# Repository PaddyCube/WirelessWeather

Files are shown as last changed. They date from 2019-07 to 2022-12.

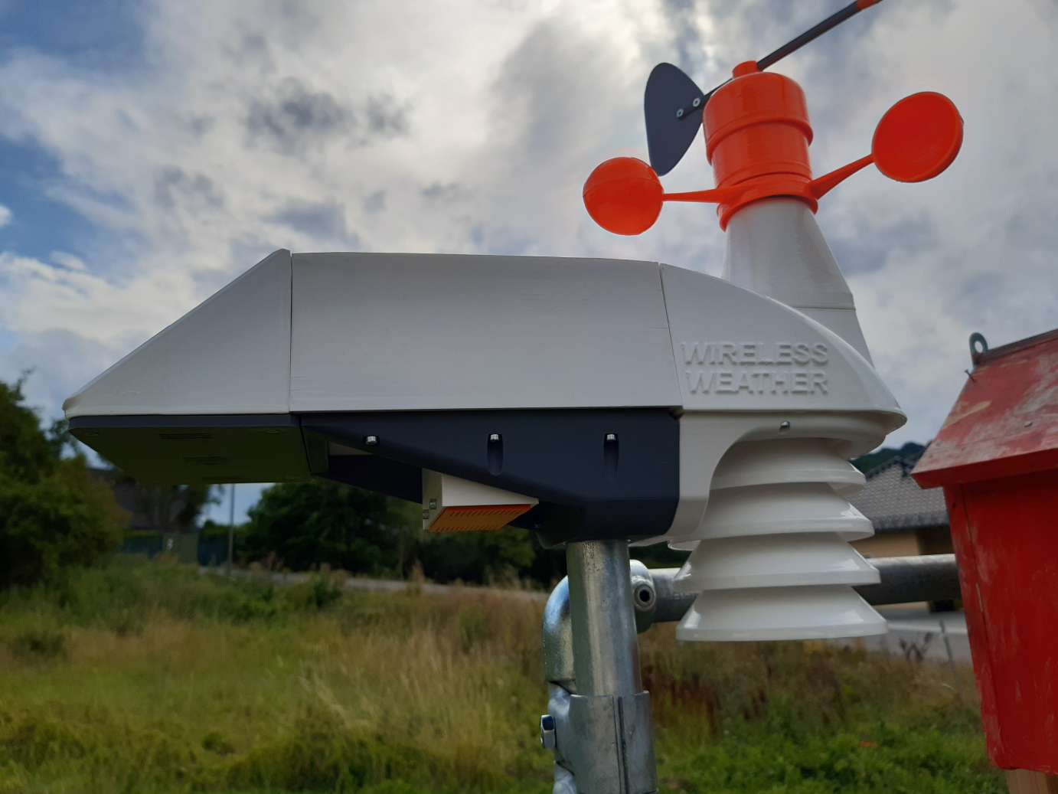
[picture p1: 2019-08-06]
Pictures/20190806_172357.jpg

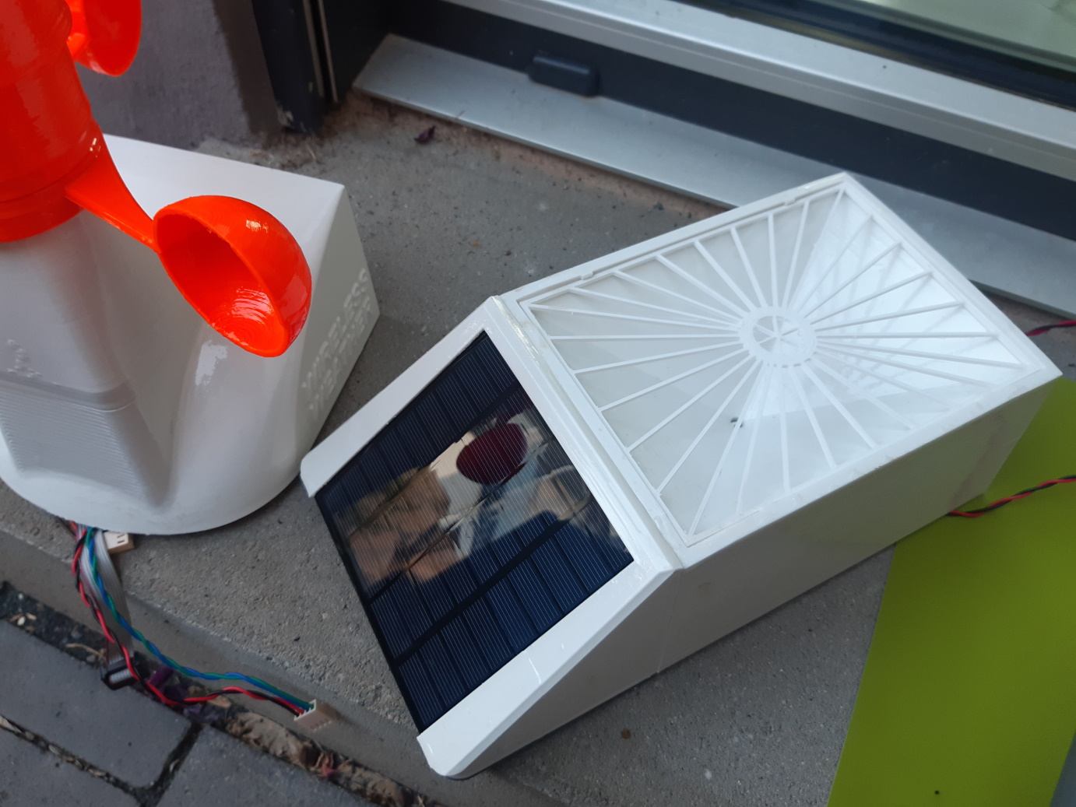
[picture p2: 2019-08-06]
Pictures/20190723_202226.jpg

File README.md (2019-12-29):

## Description
Build your own Wireless Weather station. This station includes:
- Temperature
- Humidity
- Pressure
- Rain Level
- Wind Speed
- Wind direction
- Battery monitor

There are three versions available: 
- One uses ESP8622 module and some ATTINYs
- one uses ESP32 and only one ATTINY for wind direction 
- one uses an Arduino Mini together with ATTINY24 for wind direction inside weather station and publish messages by 433 Mhz.

Code and schematics for any solution can be found in corresponding subfolders of folder 'code'

## Operation mode
### ESP8266
Wind speed and rain gets detected by pin change interrupt of ATTINYs. 
There is a power hungry device called WEMOS D1 mini pro, which deep sleeps most time. 
Every few minutes, it wakes up, collect data from other devices by I2C, send everything to your MQTT broker and sleeps again.

### ESP32
Wind speed and rain gets count by ULP co-processor of ESP32 module. Every few minutes, ESP32 wakes from deep sleep, read count values from ULP, power up I2C devices and sends everything to your MQTT broker. Then it sleeps again.

### Arduino Pro Mini
Because ESP devices are pretty power hungry, I wanted to build something more power saving. Therefore, a Arduino Pro Mini is used inside the weather station. Most time it sleeps and count wind and rain by interrupts. Every x minutes, it wakes up, power up I2C devices (BME280 and ATTINY24 for wind direction), reads values and send them using cheap 433MHz module. You find a working example based on ESP8266 module acting as a bridge between 433 Mhz and MQTT, so it receives data over 433MHz and publish them like before using MQTT. 

## Project site
You find all 3D printed parts at Thingiverse 
https://www.thingiverse.com/thing:3718078

A video is here https://youtu.be/xa0Dt5vs0kM

## BOM
This package includes software for the following components
### ESP8266
- 2x ATTINY85 (wind speed, rain and battery level)
- 1x ATTINY24 (wind direction)
- Wemos D1 Mini pro (or other ESP8266 device)
- 1x BME280
- Please find a complete BOM in BOM.txt file

Moreover you need some device to program ATTINYs. This can be done with any Arduino device. There are plenty of tutorials out there.

### ESP32
- 1x ATTINY24 (wind direction, see folder Wireless Weather)
- ESP32 (DOIT DevKit V1 with 30 GPIOs)
- 1x BME280

For further information, please see readme file in ESP32 folder

### Arduino Pro Mini
- 1x Arduino Pro Mini
- 1x ATTINY24 (wind direction)
- 1x BME280
- 1x 433MHz receiver, transmitter pair

You also need some code and device to receive the data and process them further. This can be done with any device, like Arduino, ESP8266, ESP32, Raspberry PI and so on. To get a complete working example, I added some code for ESP8266 (WEMOS D1 mini pro) which
acts as some kind of bridge between 433MHz and MQTT, meaning it receives the data send by Arduino Pro Mini and send them using MQTT protocol.

## Required Software
For ATTINYs, you need this package <br>
https://github.com/SpenceKonde/ATTinyCore <br>
https://github.com/rambo/TinyWire <br>

For ESP8266 and ESP32, I used this one <br>
https://arduino.esp8266.com/stable/package_esp8266com_index.json <br>
https://github.com/knolleary/pubsubclient <br>
https://github.com/adafruit/Adafruit_BME280_Library <br>

When using Arduino Pro mini, you need these packages as well <br>
https://github.com/rocketscream/Low-Power <br>
https://github.com/PaulStoffregen/RadioHead <br>
https://github.com/adafruit/Adafruit_BME280_Library <br>

## License
<br>Copyright (c) 2019 by Patrick Weber  

Private-use only! (you need to ask for a commercial-use)

You should have received a copy of the GNU General Public License
along with this program.  If not, see <http://www.gnu.org/licenses/>.

Private-use only! (you need to ask for a commercial-use)

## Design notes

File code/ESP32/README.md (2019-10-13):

## Description
This folder contains alternative code for ESP32 boards. By using this, less components are needed.

## Operation mode
Wind speed and rain gets detected by ESP32's built-in ULP co-processor while main ESP32 sleeps. 
Every few minutes, ESP32 wakes up, collect data from other devices by I2C, 
send everything to your MQTT broker and sleeps again.

## Project site
You find all 3D printed parts at Thingiverse 
https://www.thingiverse.com/thing:3718078

## BOM
This package includes software for the following components
- ESP32 board (I use ESP32 DEVKIT V1 with 30 GPIOs)

Because I didn't want to learn a new IDE, I used Arduino IDE to program everything (also ULP part), instead of esp-idf.
To upload ULP code with Arduino IDE, you need ulptool provided by duff2013 (https://github.com/duff2013/ulptool),
Arduino IDE itself and official packages for Arduino IDE provided by Espressif

## License
<br>Copyright (c) 2019 by Patrick Weber  

Private-use only! (you need to ask for a commercial-use)

You should have received a copy of the GNU General Public License
along with this program.  If not, see <http://www.gnu.org/licenses/>.

Private-use only! (you need to ask for a commercial-use)

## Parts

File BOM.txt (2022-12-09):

#---------------------------------------
# Screws and Nuts
#---------------------------------------
20x Knurled brass nuts (OD4mm, 5mm length) (https://www.aliexpress.com/w/wholesale-brass-insert-nut.html?switch_new_app=y)
30x Screws M3 (DIN 912)
4x Screw M4 x 60 (DIN 912)
4x Screw M4
2x Screw M5 x 40 (DIN 912)
7x counter sink screw M3 x 8 (DIN 7991)
14x Nuts M3
3x M3 threaded rod 105mm (Stevenson Screen)
8x Nuts M4
2x Nuts M5
1x Alu pipe 8mm OD 95mm
1x Alu Pipe 8mm OD 50mm
8x washer M3
4x wood or plastic screws (or knurled brass nuts + screws) (Anemometer)
2x KFL08 bearings (https://www.dold-mechatronik.de/Flanschlager-8mm-Aluminium-Druckguss-KFL08)
3x round magnet (neodym) 5mm OD

#---------------------------------------
# Electronics
#---------------------------------------
10 x Reed switch (NO)
1x Solar panel 110 x 125mm (https://www.ebay.de/itm/Mini-9V-1-5W-Sonnenkollektor-Solaranlage-Solar-Power-Panel-DIY-f%C3%BCr-Handy-Charger/272626734434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)
1x Battery case
3x AAA Nimh cells
4x Capacitor (electrolyte) 4,7uF
4x Capacitor (ceramic) 100nF
4x Capacitor (ceramic) 1uF
1x Schottky Diode SB 5100
2x Resistor 4k7
1x Resistor 1M5k
1x Resistor 220k
1x Resistor 100k
1x BME280

Next depends on the target solution you want to build

# ---- ESP8266 using ATTINYs for count wind/rain and wind direction
2x ATTINY85-20PU
1x ATTINY24A-PU
1x WEMOS D1 mini pro
1x MCP1702-3302 (https://www.reichelt.de/ldo-regler-fest-3-3-v-to-92-mcp-1702-3302-p90114.html?&trstct=pos_0)
1x MCP1702-5002 (https://www.reichelt.de/ldo-regler-fest-5-v-to-92-mcp-1702-5002-p90115.html)

# ---- ESP32 using ATTINY24 for wind direction
1x ATTINY24A-PU
1x ESP32 (DOIT DevKit V1 with 30 GPIOs)
1x MCP1826S-3302E (https://www.mouser.de/ProductDetail/Microchip-Technology/MCP1826S-3302E-AB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)
1x MCP1702-5002 

# ---- Arduino Pro Mini using ATTINY24 for wind direction
1x ATTINY24A-PU
1x Arduino Pro Mini 8Mhz, 3.3V (or ATMEGA328P)
1x MCP1702-3302 (https://www.reichelt.de/ldo-regler-fest-3-3-v-to-92-mcp-1702-3302-p90114.html?&trstct=pos_0)
1x MCP1702-5002 (https://www.reichelt.de/ldo-regler-fest-5-v-to-92-mcp-1702-5002-p90115.html)

#---------------------------------------
# Others
#---------------------------------------
Hot glue
Hot shrink tube
Wires
crimp connectors

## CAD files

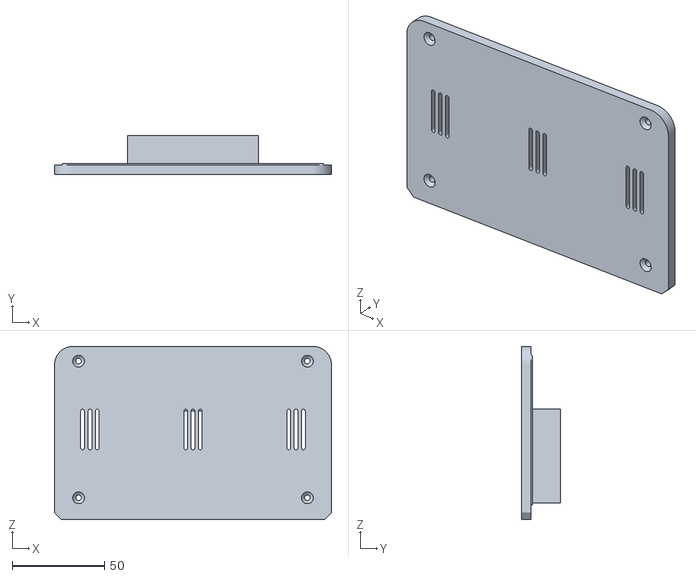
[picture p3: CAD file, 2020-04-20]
STL/Batteriefach.stl
150.0 x 21.0 x 93.8

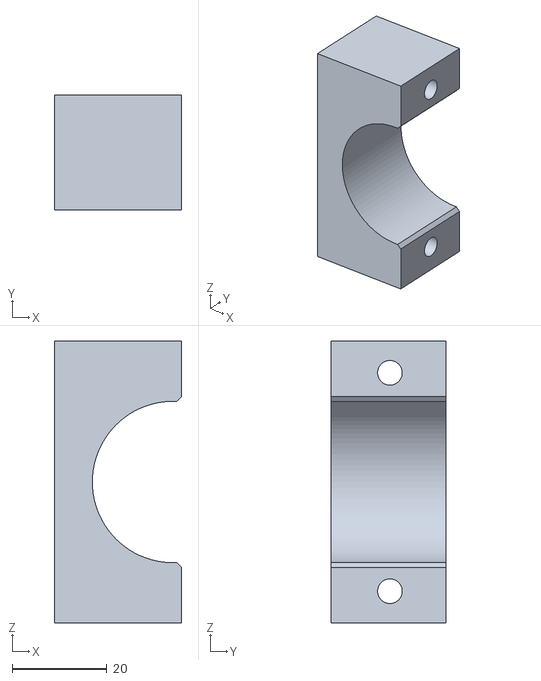
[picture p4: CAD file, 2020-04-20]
STL/Raingauge-Pole-Clamp.stl
26.8 x 24.2 x 59.4

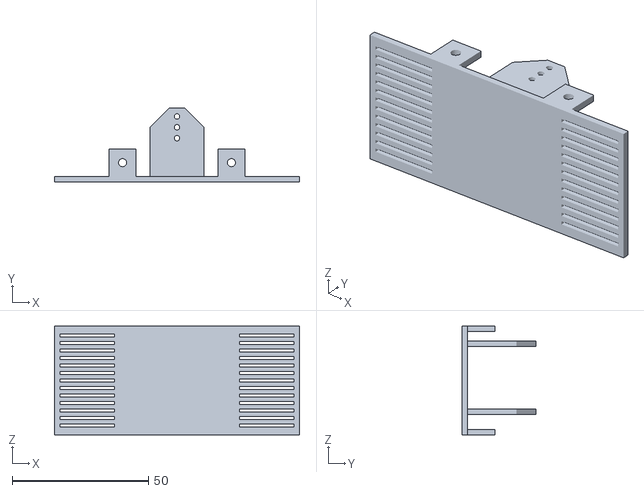
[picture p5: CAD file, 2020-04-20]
STL/Raingauge_Basis.stl
90.0 x 27.0 x 40.0

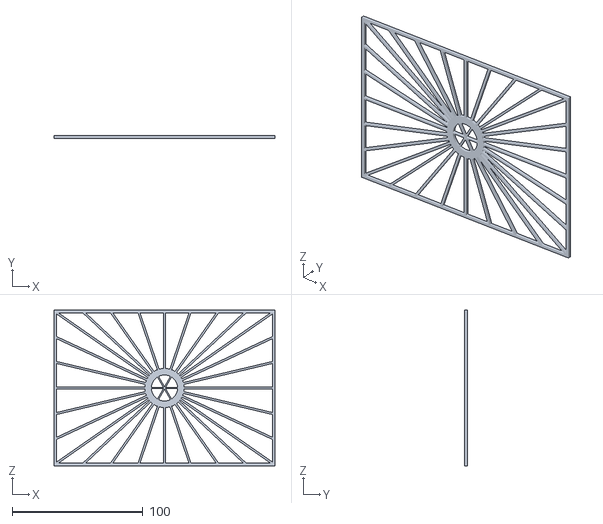
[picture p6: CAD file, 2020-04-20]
STL/Raingauge-Derb-Filter.stl
169.0 x 2.00 x 119.0

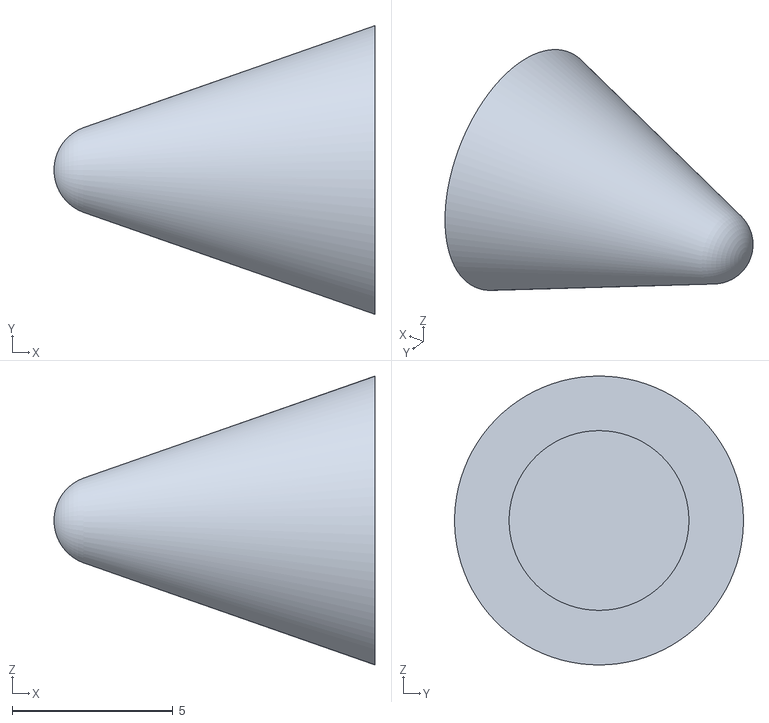
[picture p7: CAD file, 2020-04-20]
STL/Windfahne-Balance2.stl
10.0 x 8.99 x 9.00

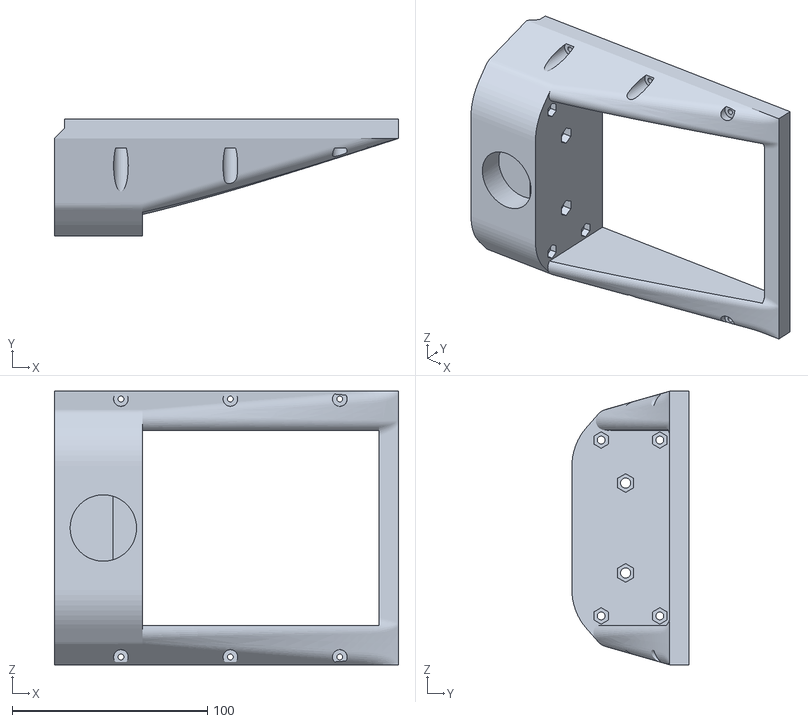
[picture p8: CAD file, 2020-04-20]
STL/Raingaube-lower-part.stl
176.0 x 60.0 x 140.0

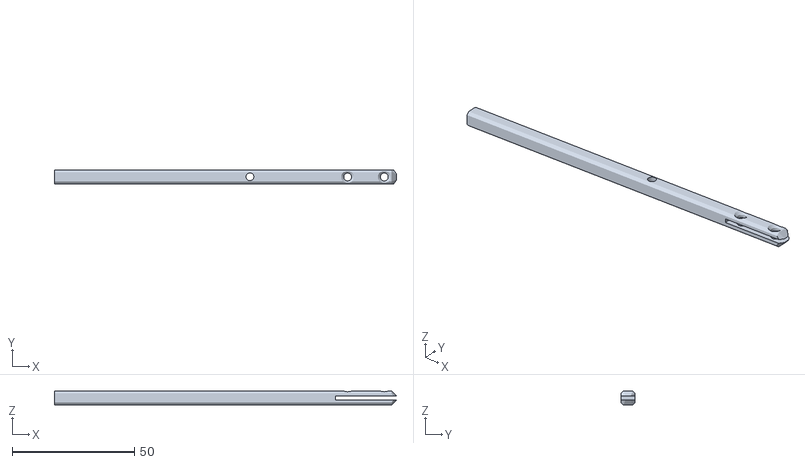
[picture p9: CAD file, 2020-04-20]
STL/Windfahne-Stab.stl
140.0 x 5.80 x 5.80

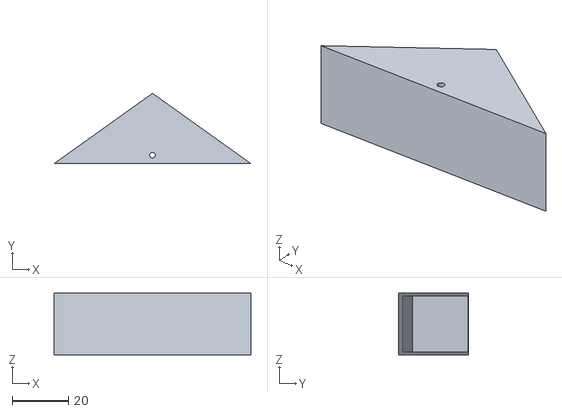
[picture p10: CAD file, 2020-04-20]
STL/Raingauge.stl
70.0 x 25.0 x 22.0

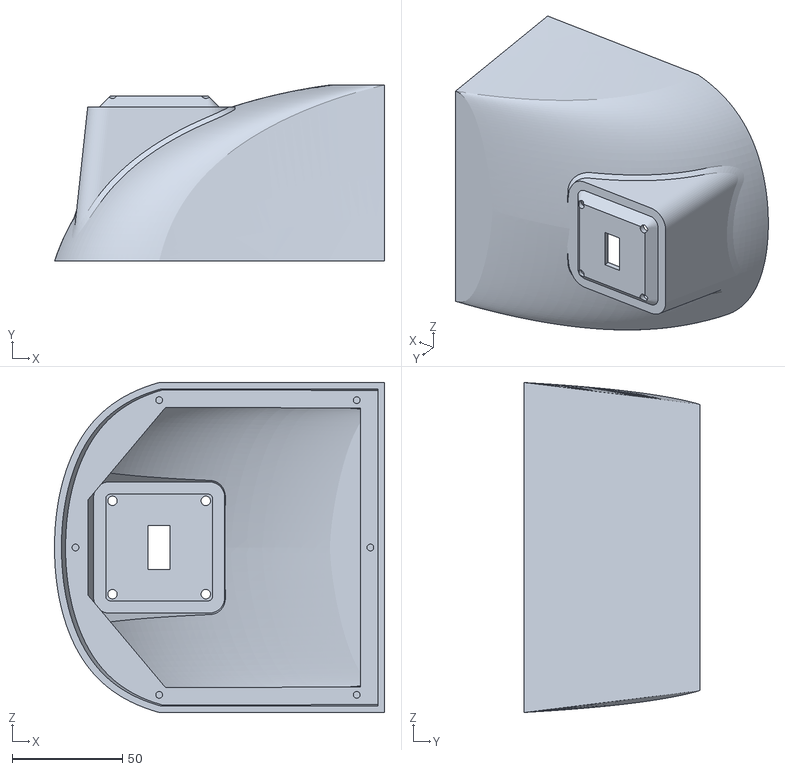
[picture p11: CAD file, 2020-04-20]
STL/Body7.stl
150.0 x 80.0 x 150.0

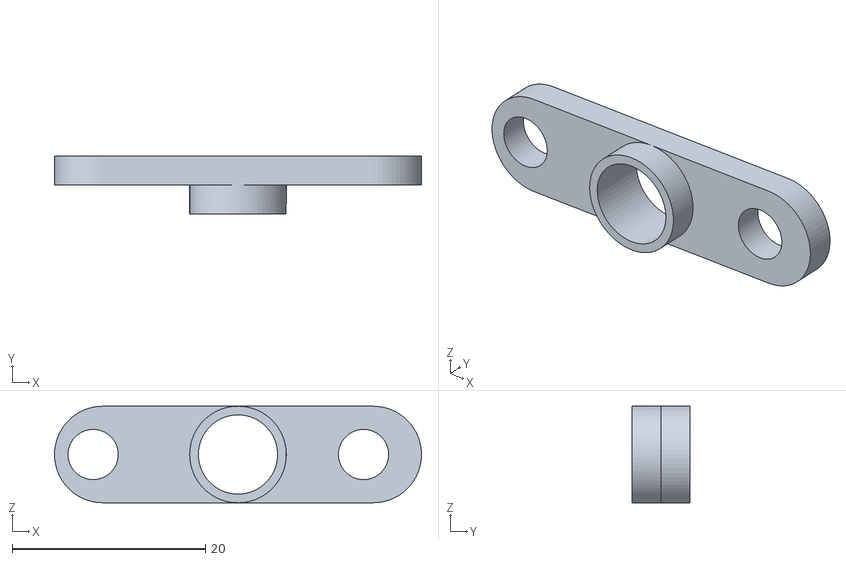
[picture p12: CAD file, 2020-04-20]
STL/Windfahne-Magnet.stl
38.0 x 6.00 x 10.0

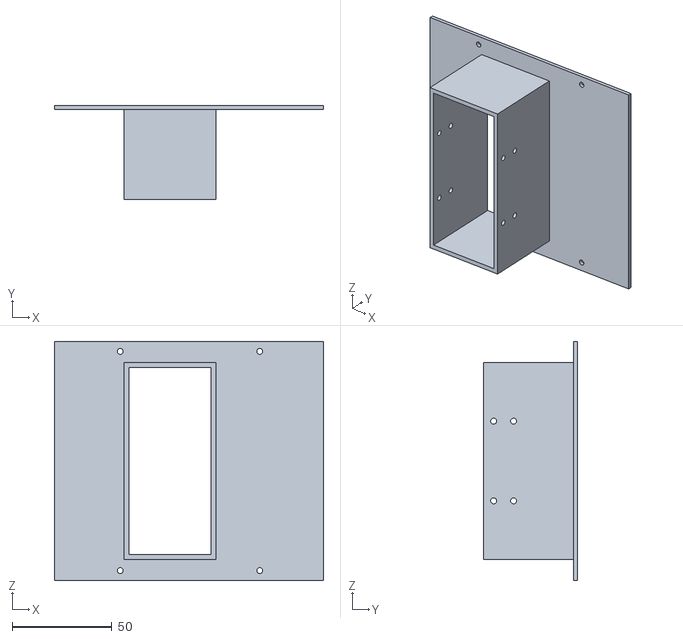
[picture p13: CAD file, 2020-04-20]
STL/Raingauge-mount-plate.stl
135.0 x 47.0 x 120.0

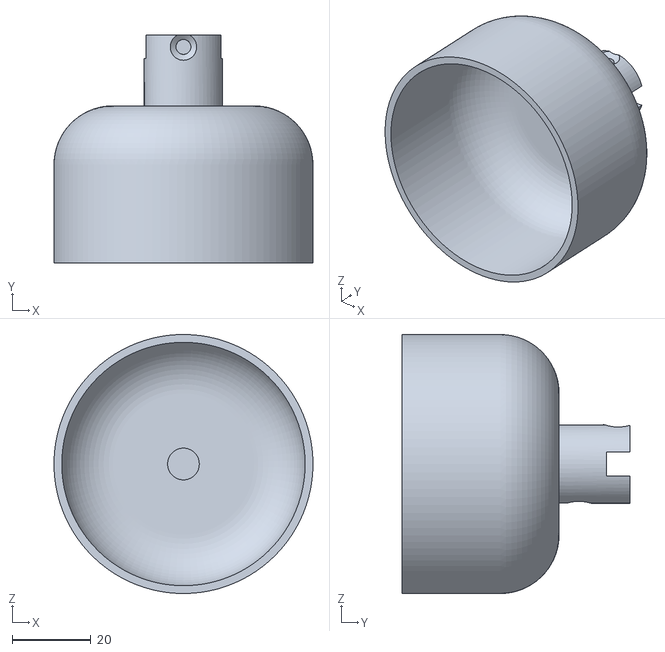
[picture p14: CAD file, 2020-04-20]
STL/Windfahne-Haube.stl
66.0 x 58.0 x 66.0

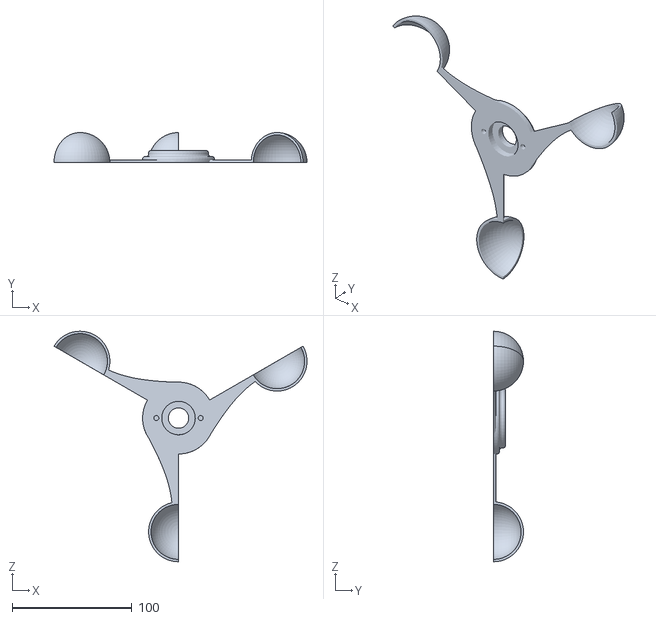
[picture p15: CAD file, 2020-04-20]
STL/Anemometer-Lagerschale.stl
211.2 x 25.0 x 192.5

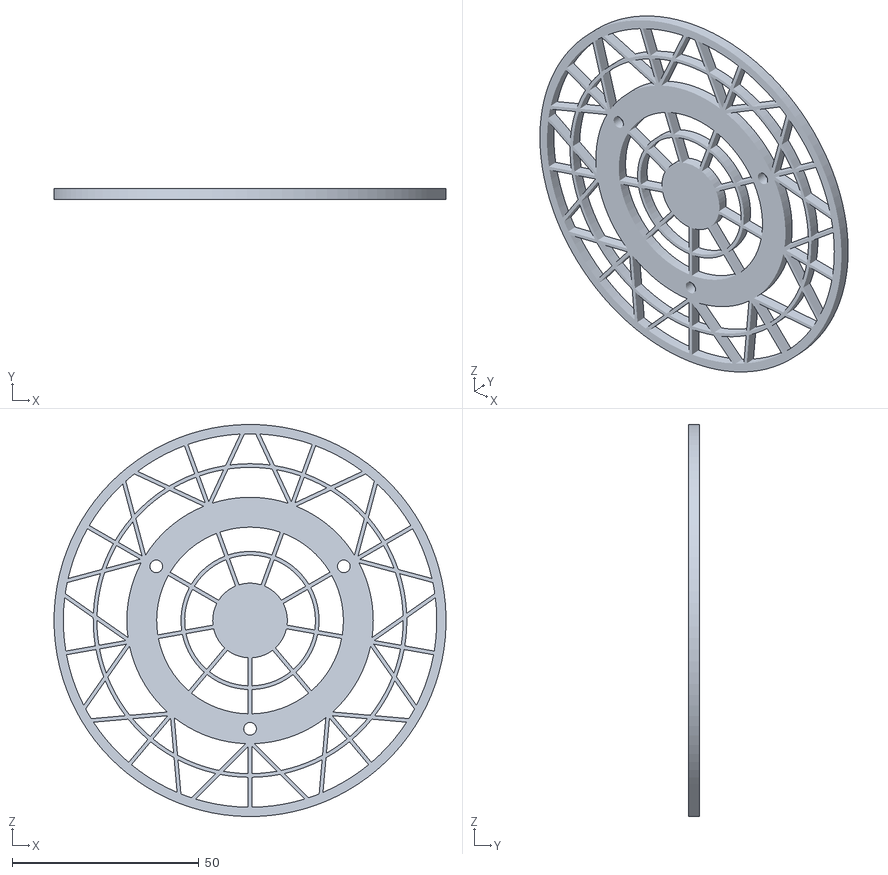
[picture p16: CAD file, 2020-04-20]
STL/Stevenson-Screen-Boden.stl
105.0 x 3.00 x 105.0

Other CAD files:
STL/Anemometer-lower-part v17.stl
STL/Sensor-Mount.stl
STL/Rain_Gauge_Cover.stl
STL/Solar-Modul.stl
STL/Anemometer-Lagerschale (1).stl
STL/Anemometer-lower-part v16.stl
STL/Anemometer-lower-part_v17.stl
STL/Platinenhalter.stl
STL/Stevenson-Screen-Mittelteil.stl
STL/Wetterstation-upper-part.stl
STL/Windfahne-Balance1.stl
STL/Windfahne-Deckel.stl
STL/Windfahne-Mast.stl
STL/Windfahne-Paddel.stl
STL/Windfahne-unten (1).stl
STL/Windfahne-unten.stl

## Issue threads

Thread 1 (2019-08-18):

PCB files cannot be opened.

theshadowsvk, 2019-08-18:
Hello PaddyCube, first of all, thank you for your great project !! All your solutions done in this project are simply perfect !!
My issue is, I can't oped the PCB files, especially those KiCad (it needs .zip filed them in some sort of way) or Eagle files, that this EDA wants them to be saved in Eagle 6.0 or above.
I'm trying to import these in EasyEDA. If you have some time, can you check it please ?

Thank you,
Lubos

PaddyCube, 2019-09-26:
Hello,
thank you for your feedback. Saldy I didn't note it, sorry for my late response. I'm not sure if I understand you right. I didn't create a PCB, its just a schematics drawing and I used KiCad to greate schematics. Currently, I don't know how to create a PCB file so you can manufacture it.

But as an additional note: I'm working on a ESP32 version of my weather station. That way, I can at least drop the two ATTINY85 because I use ULP co-processor to count while sleep.

theshadowsvk, 2019-09-26:
Oh sorry I thought they are pcb files. I already re-created the schematics and started creating pcb. Btw, I do some enhancements there like light sensor on i2c bus and other things like easier voltage regulator, solar charge

Esp32 supports various deepsleeps

PaddyCube, 2019-09-27:
May I ask which voltage regulator you use? MCP1703 does a good job but it delivers not enough current (250mA max). Sometimes, ESP8266 with all three Attinys will brownout and I must hard reset everything. I'm looking for a larger LDO for ESP32, so any suggestions?

PaddyCube, 2019-12-29:
Only schematics are available. I used prototype boards to solder everything together. Meaning there is no ready-to use PCB file

Closed 2019-12-29.

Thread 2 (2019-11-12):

Viewing received data

jeffreyclay, 2019-11-12:
I don't see anything mentioned regarding viewing or recording the data. Am I missing something?

PaddyCube, 2019-12-29:
Hi, this weather station uses MQTT to send data. So it is up to you to install a MQTT broker where the station can send data to.

There is a newer Version using a Arduino Pro Mini and a 433 MHz Transmitter to send data. Also there is some example code where ESP8266 device acts as receiver and send data (again) using MQTT. As a MQTT target, you can also use something like Thingspeak.com

Closed 2019-12-29.

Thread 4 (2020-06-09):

Schaltplan Arduino Mini

Marmi86, 2020-06-09:
Sehr schönes Projekt,
gib es für den Arduino mini/Nano auch ein Schaltplan für die Pinoutbelegung

Mfg
Marco

notecp, 2021-01-13:
So geht es mir auch, klasse Projekt.
Ich würde es ebenfalls nachbauen wollen und würde mich an KiCAD und Platinenlayout versuchen wollen (und diese hier zur Verfügung stellen)... wenn ich sicher wüsste, was wie verbunden gehört. Ebenso was den 433MHz Receiver angeht.

VG
Christian

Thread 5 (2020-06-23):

screw length

corneliusweiss, 2020-06-23:
Hi,
thanks for sharing your project. I'd like to build a copy for me.

Can you share the screw length in the BOM.txt with us?

kind regards
Cornelius

leonundjulie, 2023-12-21:
Hi to all of you. I am ready to screw parts …. §D-printing finished last night :-)

However, is someone able to tell us new story-member the length of the different types of screws?

Regards from
Andreas

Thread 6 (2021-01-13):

Lichtsensor / Fassade in der Sonne?

notecp, 2021-01-13:
Hallo Paddy,

gibt es eine Planung / Möglichkeit einen Lichtsensor o.ä. sinnvoll in die Station zu Integrieren?
Falls ja, würde sich doch damit auch schnell berechnen lassen wo die Sonne aktuell steht und ob sie auch wirklich scheint, oder?

Alternativ habe ich mir überlegt müsste es doch auch möglich sein (ob sinnvoll bin ich mir nicht sicher) einen Temperaturfühler an der Ost, Süd und Westseite anzubringen und diesen mit dem bereits vorhandenen zu vergleichen. Somit müsste es möglich sein festzustellen, ob die Station von dieser Seite in der Sonne steht oder nicht, oder?

VG
Christian

AcidSubway, 2022-01-16:
da ich grad über diesem Projekt bin, wäre ein Lux-Sensor schon cool :D

leonundjulie, 2023-12-21:
Hast Du das Projekt umgesetzt? Ich suche gerade nach den Längen der Schrauben??

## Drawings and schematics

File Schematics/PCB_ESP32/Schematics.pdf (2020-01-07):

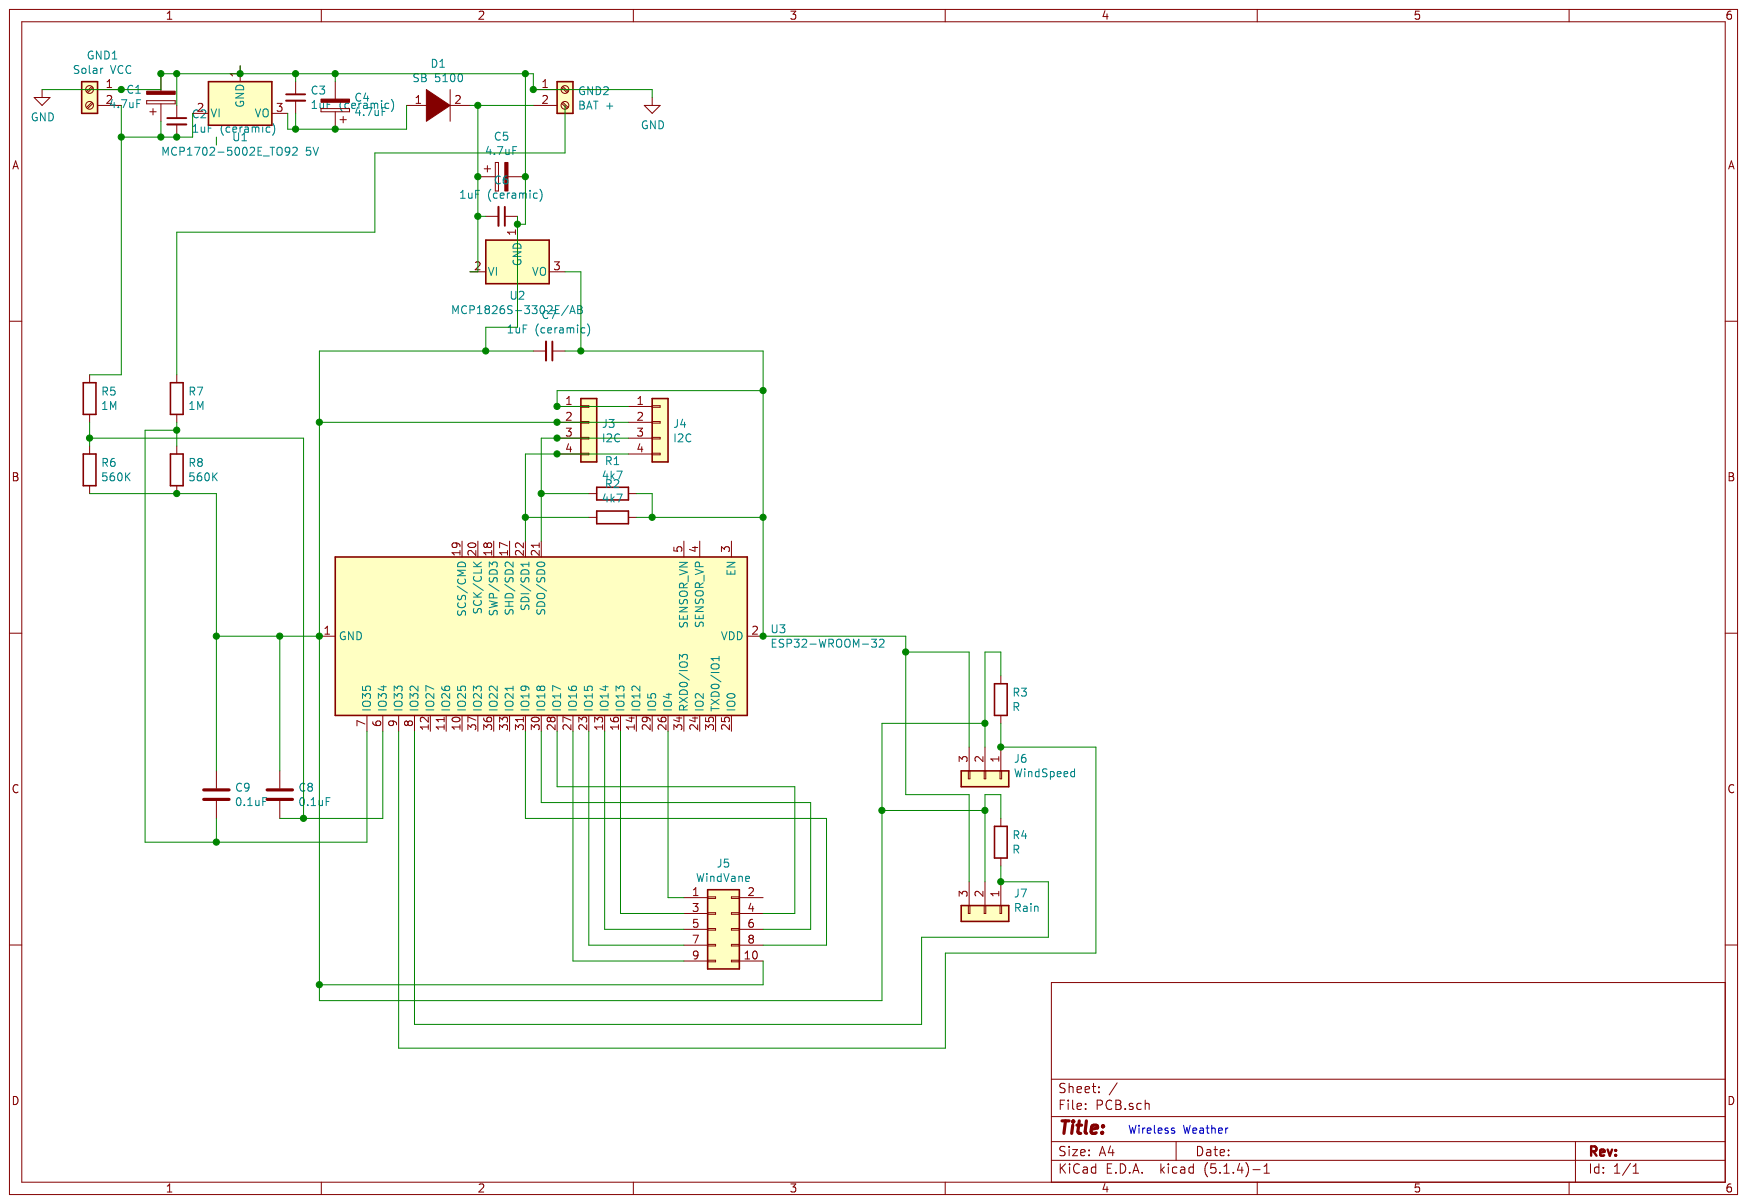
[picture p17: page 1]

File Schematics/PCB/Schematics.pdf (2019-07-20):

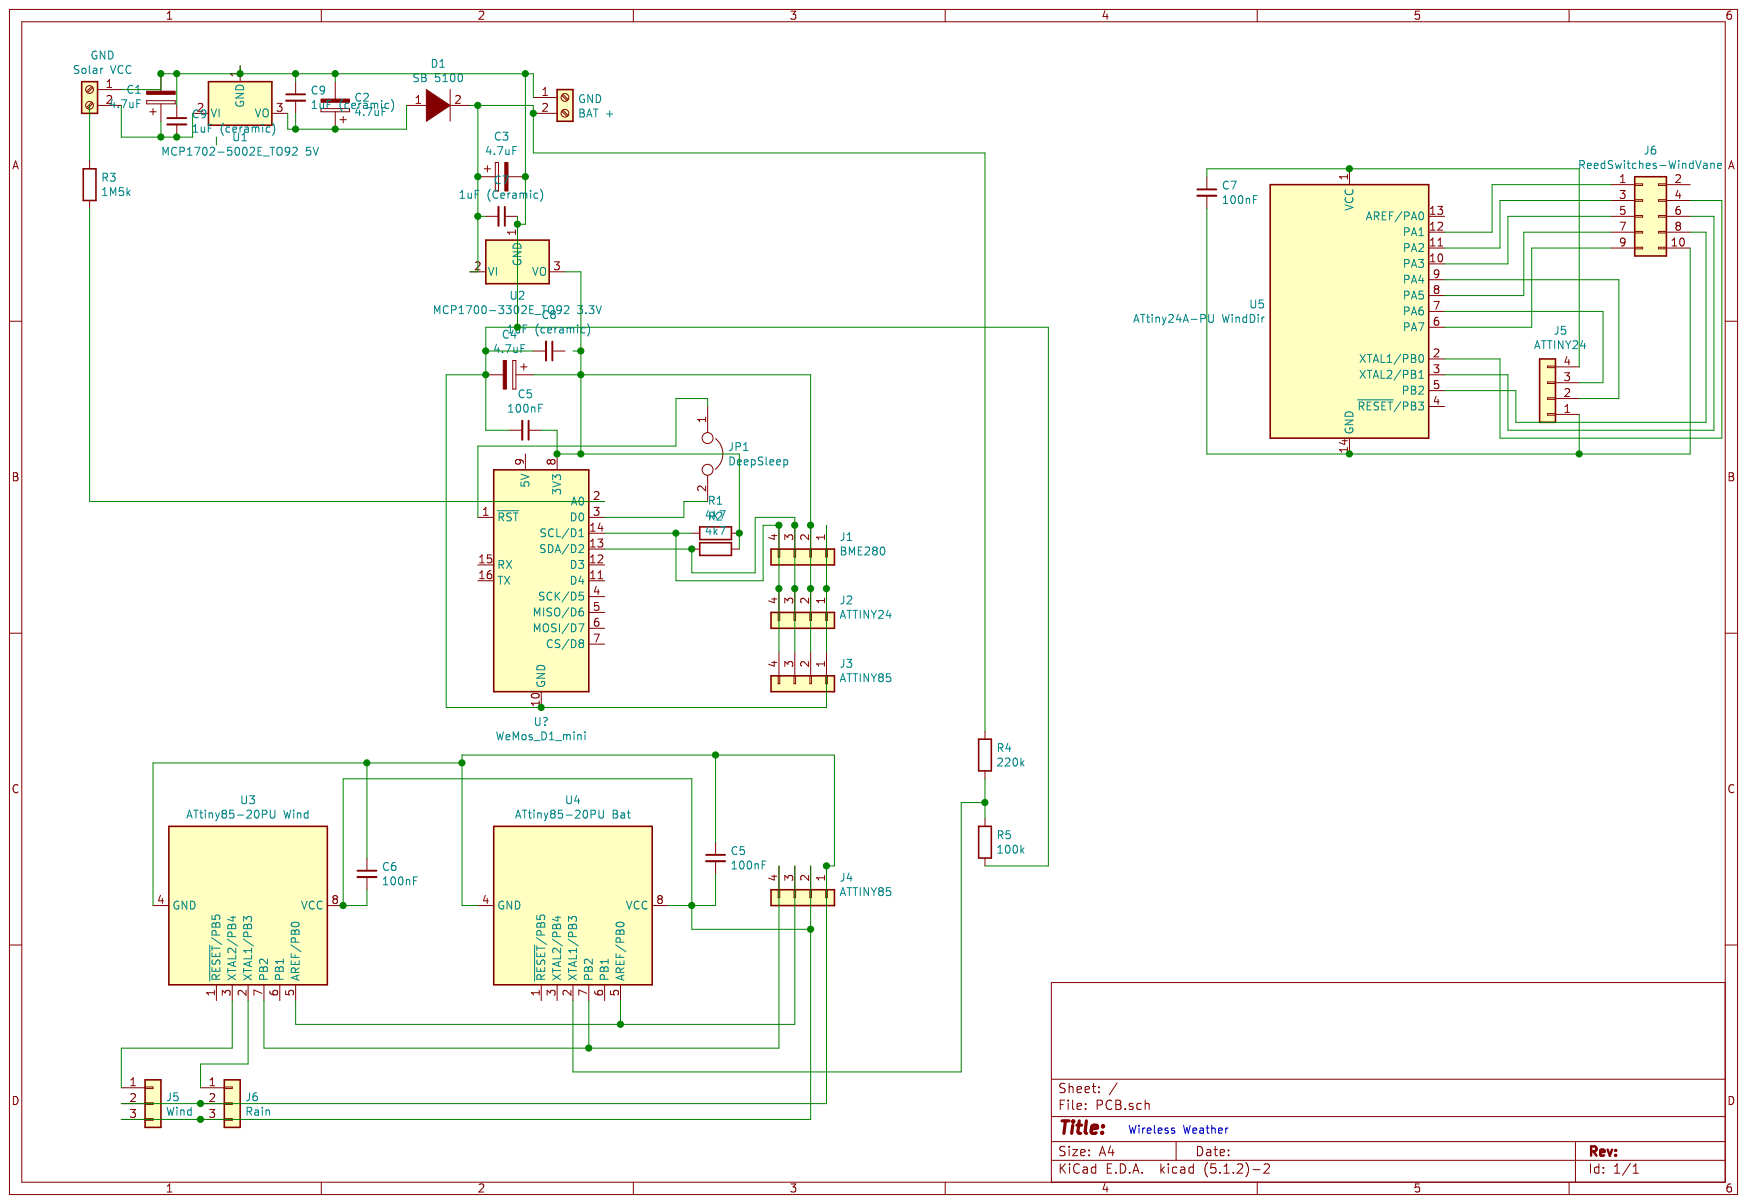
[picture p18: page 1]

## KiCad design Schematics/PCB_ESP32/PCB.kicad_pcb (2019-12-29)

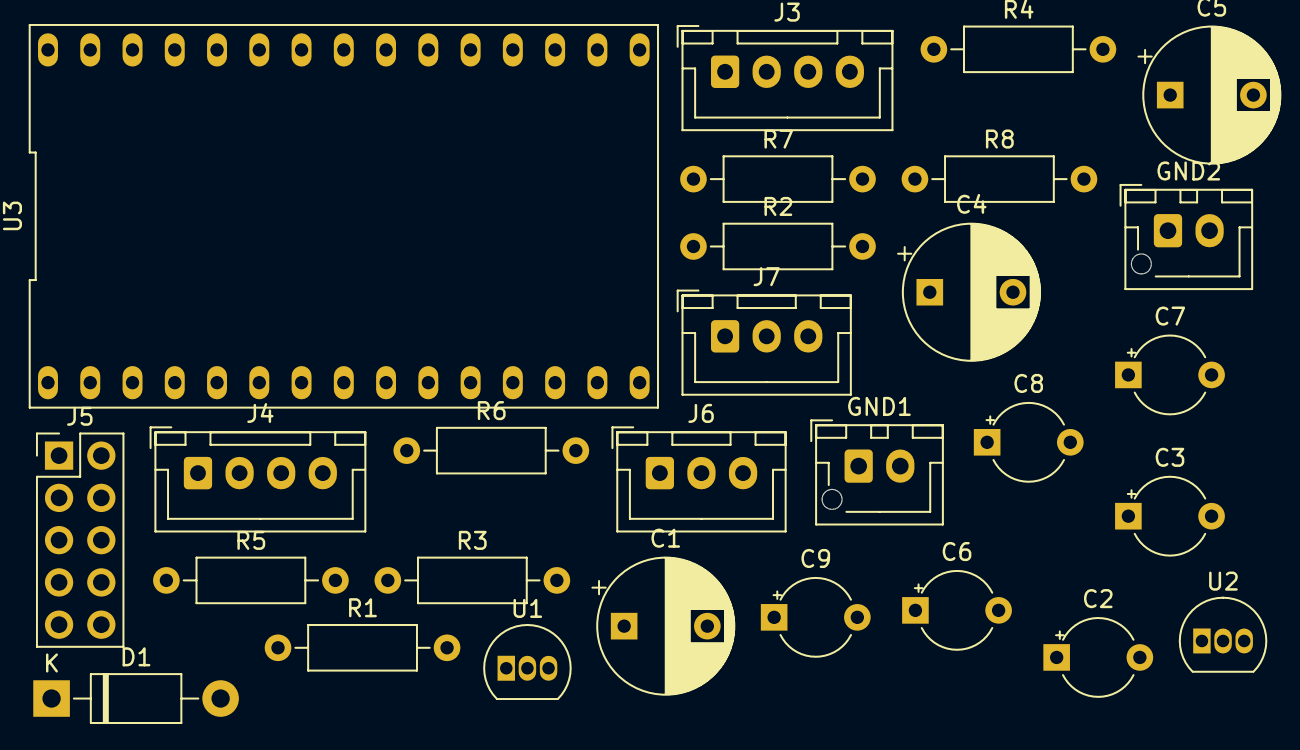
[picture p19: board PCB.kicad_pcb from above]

Board: 2 copper layers, 28 parts (0 on the bottom side), 12 nets, no tracks yet.

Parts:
C1, C4, C5: 4.7uF; CP_Radial_D8.0mm_P5.00mm
C2, C3, C6, C7: 1uF (ceramic); CP_Radial_Tantal_D4.5mm_P5.00mm
C8, C9: 0.1uF; CP_Radial_Tantal_D4.5mm_P5.00mm
D1: SB 5100; D_DO-41_SOD81_P10.16mm_Horizontal
GND1: Solar VCC; JST_XH_B2B-XH-AM_1x02_P2.50mm_Vertical
GND2: BAT +; JST_XH_B2B-XH-AM_1x02_P2.50mm_Vertical
J3, J4: I2C; JST_XH_B4B-XH-A_1x04_P2.50mm_Vertical
J5: WindVane; PinHeader_2x05_P2.54mm_Vertical
J6: WindSpeed; JST_XH_B3B-XH-A_1x03_P2.50mm_Vertical
J7: Rain; JST_XH_B3B-XH-A_1x03_P2.50mm_Vertical
R1, R2: 4k7; R_Axial_DIN0207_L6.3mm_D2.5mm_P10.16mm_Horizontal
R3, R4: R; R_Axial_DIN0207_L6.3mm_D2.5mm_P10.16mm_Horizontal
R5: 20M; R_Axial_DIN0207_L6.3mm_D2.5mm_P10.16mm_Horizontal
R6, R8: 10M; R_Axial_DIN0207_L6.3mm_D2.5mm_P10.16mm_Horizontal
R7: 5M2; R_Axial_DIN0207_L6.3mm_D2.5mm_P10.16mm_Horizontal
U1: MCP1702-5002E_TO92 5V; TO-92_Inline
U2: MCP1700-3302E_TO92 3.3V; TO-92_Inline
U3: ESP32-WROOM-32; ESP32DevKit

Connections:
GND: C1.2, C2.1, C3.1, C4.2, C5.2, C6.1, C7.2, C8.1, C9.1, GND1.1, GND2.1, J3.2, J4.2, J5.10, J6.2, J7.2, R6.2, R8.2, U1.1, U2.1, U3.1, U3.15
unnamed: C1.1, C2.2, GND1.2, R5.1, U1.2
unnamed: C3.2, C4.1, D1.1, U1.3
unnamed: C5.1, C6.2, D1.2, GND2.2, U2.2
unnamed: C7.1, J3.1, J4.1, J6.3, J7.3, R1.1, R2.1, R3.1, R4.1, U2.3, U3.2
unnamed: C8.2, R5.2, R6.1, U3.6
unnamed: C9.2, R7.2, R8.1, U3.7
unnamed: J3.3, J4.3, R1.2
unnamed: J3.4, J4.4, R2.2
unnamed: J5.5, U3.13
unnamed: J6.1, R3.2, U3.9
unnamed: J7.1, R4.2, U3.8

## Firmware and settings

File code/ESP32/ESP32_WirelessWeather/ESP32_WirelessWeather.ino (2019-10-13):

/* Solar powered WIFI weather station using ESP32.

   Wind speed and rain gets detected by ESP32's built-in ULP co-processor while main ESP32 sleeps.
   Every few minutes, ESP32 wakes up, collect data from other devices by I2C,
   send everything to your MQTT broker and sleeps again.

   Please take note of settings.h
   Here you find wfi related settings, connection settings to MQTT, sleep settings and others

   Because I didn't want to learn a new IDE, I used Ardiono IDE to program everything (also ULP part), instead of esp-idf.
   To upload ULP code with Arduino IDE, you need ulptool provided by duff2013 (https://github.com/duff2013/ulptool),
   Arduino IDE itself and official packages for Arduino IDE provided by Espressif

   Copyright (c) 2019 by Patrick Weber

   Private-use only! (you need to ask for a commercial-use)

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
  Private-use only! (you need to ask for a commercial-use)
*/


#include <stdio.h>
#include "esp_sleep.h"
#include "nvs.h"
#include "nvs_flash.h"
#include "soc/rtc_cntl_reg.h"
#include "soc/sens_reg.h"
#include "soc/rtc_periph.h"
#include "driver/gpio.h"
#include "driver/rtc_io.h"
#include "settings.h"
#include "driver/adc.h"
#include <Adafruit_BME280.h>
#include "WindVane.h"
#include <WiFi.h>
#include <PubSubClient.h>
//#include <Wire.h>

#include "esp32/ulp.h"// Must have this!!!

// include ulp header you will create
#include "ulp_main.h"// Must have this!!!

// Custom binary loader
#include "ulptool.h"// Must have this!!!

// Unlike the esp-idf always use these binary blob names
extern const uint8_t ulp_main_bin_start[] asm("_binary_ulp_main_bin_start");
extern const uint8_t ulp_main_bin_end[]   asm("_binary_ulp_main_bin_end");

WiFiClient espClient;
PubSubClient client(espClient);
WindVane windvane;
Adafruit_BME280 bme;

long lastMsg = 0;
char msg[50];
int value = 0;
char temp[10];
char pressure[10];
char humidity[10];
char windvalue[10];
char rainvalue[10];
char windpos[4];
char batvalue[10];
char solarvalue[10];

static void init_ulp_program(void);
static void update_pulse_count(void);
static void pin_setup(gpio_num_t gpio_num);
static void measureVoltage(void);
static void sleep();

/*--------------------------------------------------
   setup gets called on each boot and on each wakeup
  --------------------------------------------------*/
void setup(void)
{
  btStop();

  pinMode(i2cVccPin, OUTPUT);
  digitalWrite(i2cVccPin, HIGH);

  Serial.begin(115200);
  windvane.begin();
  Serial.println(bme.begin(0x76));


  setup_wifi();
  client.setServer(MQTT_BROKER, MQTT_PORT);

  esp_sleep_wakeup_cause_t cause = esp_sleep_get_wakeup_cause();
  if (cause != ESP_SLEEP_WAKEUP_TIMER) {
    printf("No TIMER wakeup, initializing ULP\n");
    init_ulp_program();
  } else {
    printf("TIMER wakeup, saving pulse count\n");
    client.setServer(MQTT_BROKER, MQTT_PORT);
    update_pulse_count();
  }
}

/*--------------------------------------------------
   loop
  --------------------------------------------------*/

void loop() {
  float lv_temp;
  float lv_pressure;
  float lv_humidity;
  unsigned int lv_wind;
  unsigned int lv_rain;
  unsigned int lv_battery;

  // prepare deep sleep
  ESP_ERROR_CHECK( esp_sleep_enable_timer_wakeup(SLEEP_MIN * 60 * 1000000) );

  // connecting to MQTT broker
  if (!client.connected()) {
    reconnect();
  }
  client.loop();

  snprintf (msg, 50, "Alive since %ld milliseconds", millis());
  Serial.print("Publish message: ");
  Serial.println(msg);

  // Read data from BME280
  lv_temp = bme.readTemperature();
  lv_pressure = bme.readPressure();
  lv_humidity = bme.readHumidity();
  delay(20);
  lv_temp = lv_temp +  bme.readTemperature();
  lv_pressure = lv_pressure + bme.readPressure();
  lv_humidity = lv_humidity + bme.readHumidity();
  delay(20);
  lv_temp = lv_temp + bme.readTemperature();
  lv_pressure = lv_pressure + bme.readPressure();
  lv_humidity = lv_humidity + bme.readHumidity();

  lv_temp = lv_temp / 3.0f;
  lv_pressure = lv_pressure / 3.0f;
  lv_humidity = lv_humidity / 3.0f;

  // convert results to char
  dtostrf(lv_temp, 6, 2, temp);
  dtostrf(lv_pressure, 6, 2, pressure);
  dtostrf(lv_humidity, 6, 2, humidity);


  delay(20);
  windvane.getCharPosition(windpos);

  // read battery and solar voltage
  measureVoltage();

  //send by MQTT

  client.publish("/WirelessWeather/Solar", solarvalue);
  client.publish("/WirelessWeather/Temperature", temp );
  client.publish("/WirelessWeather/Pressure", pressure );
  client.publish("/WirelessWeather/Humidity", humidity );
  client.publish("/WirelessWeather/Wind", windvalue );
  client.publish("/WirelessWeather/Rain", rainvalue );
  client.publish("/WirelessWeather/WindDir", windpos );
  client.publish("/WirelessWeather/Battery", batvalue);

  printf("Entering deep sleep\n\n");
  sleep();
}

/*--------------------------------------------------
   This function loads ULP programm to ULP-co processor
  --------------------------------------------------*/
static void init_ulp_program(void)
{
  esp_err_t err = ulp_load_binary(0, ulp_main_bin_start,
                                  (ulp_main_bin_end - ulp_main_bin_start) / sizeof(uint32_t));
  ESP_ERROR_CHECK(err);

  /* GPIO used for pulse counting. */
  assert(rtc_gpio_desc[GPIO_WIND].reg && "GPIO used for pulse counting must be an RTC IO");
  assert(rtc_gpio_desc[GPIO_RAIN].reg && "GPIO used for pulse counting must be an RTC IO");

  /* Initialize some variables used by ULP program.
     Each 'ulp_xyz' variable corresponds to 'xyz' variable in the ULP program.
     These variables are declared in an auto generated header file,
     'ulp_main.h', name of this file is defined in component.mk as ULP_APP_NAME.
     These variables are located in RTC_SLOW_MEM and can be accessed both by the
     ULP and the main CPUs.

     Note that the ULP reads only the lower 16 bits of these variables.
  */
  ulp_debounce_counter_wind = 2;
  ulp_debounce_counter_rain = 2;
  ulp_debounce_max_count = 3;
  ulp_next_edge_wind = 0;
  ulp_next_edge_rain = 0;
  ulp_io_number_wind = rtc_gpio_desc[GPIO_WIND].rtc_num; /* map from GPIO# to RTC_IO# */
  ulp_io_number_rain = rtc_gpio_desc[GPIO_RAIN].rtc_num; /* map from GPIO# to RTC_IO# */

  /* Initialize selected GPIO as RTC IO, enable input, disable pullup and pulldown */
  pin_setup(GPIO_WIND);
  pin_setup(GPIO_RAIN);

  /* Disconnect GPIO12 and GPIO15 to remove current drain through
     pullup/pulldown resistors.
     GPIO12 may be pulled high to select flash voltage.
  */
  rtc_gpio_isolate(GPIO_NUM_12);
  rtc_gpio_isolate(GPIO_NUM_15);
  esp_deep_sleep_disable_rom_logging(); // suppress boot messages

  /* Set ULP wake up period to T = 20ms.
     Minimum pulse width has to be T * (ulp_debounce_counter + 1) = 80ms.
  */
  ulp_set_wakeup_period(0, ULP_SLEEP_MS * 1000);

  /* Start the program */
  err = ulp_run(&ulp_entry - RTC_SLOW_MEM);
  ESP_ERROR_CHECK(err);
}

/*--------------------------------------------------
   This function shows last pulse counts
  --------------------------------------------------*/
static void update_pulse_count(void)
{


  /* ULP program counts signal edges, convert that to the number of pulses */
  uint32_t pulse_count_from_ulp_wind = (ulp_edge_count_wind & UINT16_MAX) / 2;
  /* In case of an odd number of edges, keep one until next time */
  ulp_edge_count_wind = ulp_edge_count_wind % 2;
  printf("Pulse count from wind sensor: %5d\n", pulse_count_from_ulp_wind);

  /* ULP program counts signal edges, convert that to the number of pulses */
  uint32_t pulse_count_from_ulp_rain = (ulp_edge_count_rain & UINT16_MAX) / 2;
  /* In case of an odd number of edges, keep one until next time */
  ulp_edge_count_rain = ulp_edge_count_rain % 2;
  printf("Pulse count from rain sensor: %5d\n", pulse_count_from_ulp_rain);

  itoa(pulse_count_from_ulp_wind, windvalue, 10);
  itoa(pulse_count_from_ulp_rain, rainvalue, 10);
}

/*--------------------------------------------------
   This function prepares RTC_GPIO for ULP program
  --------------------------------------------------*/
static void pin_setup(gpio_num_t gpio_num)
{
  rtc_gpio_init(gpio_num);
  rtc_gpio_set_direction(gpio_num, RTC_GPIO_MODE_INPUT_ONLY);
  rtc_gpio_pulldown_dis(gpio_num);
  rtc_gpio_pullup_dis(gpio_num);
  rtc_gpio_hold_en(gpio_num);
}


/*--------------------------------------------------
   This function connects ESP32 to WIFI
  --------------------------------------------------*/
void setup_wifi() {
  WiFi.setHostname("ESP32WirelessWeather");
  delay(10);
  // We start by connecting to a WiFi network
  Serial.print("Connecting to ");
  Serial.print(SSID);

  WiFi.begin(SSID, PSK);

  while (WiFi.status() != WL_CONNECTED) {
    delay(500);
    Serial.print(".");
  }

  Serial.println("");
  Serial.println("WiFi connected");
  Serial.print("IP address: ");
  Serial.println(WiFi.localIP());
}
/*--------------------------------------------------
   This function reconnects to MQTT broker
  --------------------------------------------------*/
void reconnect() {

  int mqtt_timeout = 0;
  while (!client.connected() && mqtt_timeout < 5) {
    Serial.println("Reconnecting to MQTT broker...");
    if (!client.connect("ESP32Client")) {
      Serial.println("failed, rc=");
      Serial.println(client.state());
      mqtt_timeout++;

      if (mqtt_timeout >= 5)
      {
        Serial.print("Error connecting to MQTT broker, sleep ");
        delay(100);
        sleep();
      } else {
        Serial.println(" retrying in 5 seconds");
        delay(5000);
      }
    }
  }
}

/*--------------------------------------------------
   This function measures voltage
  --------------------------------------------------*/
static void measureVoltage() {

  // Voltage divider R1 = 220k+100k+220k =540k and R2=100k

  // battery
  int raw = analogRead(adc_battery);
  // 1MOhm / 560kOhm * ref_voltage / 12bit ADC
  float volt = (1000.0f / 560.0f) * 3.30f * float(raw) / 4096.0f * calib_factor_battery;
  dtostrf(volt, 6, 2, batvalue);
  Serial.print( "Voltage Battery = ");
  Serial.print(batvalue);
  Serial.println (" V");

  // solar
  raw = analogRead(adc_solar);
  // 1MOhm / 560kOhm * ref_voltage / 12bit ADC
  volt = (1000.0f / 560.0f) * 3.30f * float(raw) / 4096.0f * calib_factor_solar;
  dtostrf(volt, 6, 2, solarvalue);
  Serial.print( "Voltage Solar = ");
  Serial.print(solarvalue);
  Serial.println (" V");
}

/*--------------------------------------------------
   This function prepares everything for deep sleep
  --------------------------------------------------*/
static void sleep()
{
  digitalWrite(i2cVccPin, LOW);
  delay(1000); // Time to complete all WiFi transmissions
  adc_power_off();
  WiFi.disconnect();
  WiFi.mode(WIFI_OFF);
  delay(100);

  esp_deep_sleep_start();
}

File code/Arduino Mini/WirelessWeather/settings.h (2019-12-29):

// Sleep settings (max sleep in min, only occurs if no wind or rain)
// Wind an rain trigger interrupt which gets counted as wakeup. So when high wind or lot of rain
// occur, update interval is less than 15 min)
const int SLEEP_MIN = 15;

// Pins for wind and rain count
const int WindPin = 2;
const int RainPin = 3;

// pin for data send
const int SendPin = 12;
const int SendPower = 11;

// power for I2C devices
const int i2cPower = 5;

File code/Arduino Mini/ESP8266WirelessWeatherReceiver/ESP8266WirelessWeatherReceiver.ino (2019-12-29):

#include <ESP8266WiFi.h>
#include <PubSubClient.h>
#include "settings.h"
#include <RH_ASK.h>
#include <SPI.h> // may be not relevant at all

WiFiClient espClient;
PubSubClient client(espClient);

uint8_t msg[90]; // buffer for incoming messages

RH_ASK radioHead(2000, 5, 5, 0);

void setup()
{

  Serial.begin(19200);
  setup_wifi();
  client.setServer(MQTT_BROKER, MQTT_PORT);
  Serial.println("alive");
  if (!radioHead.init())
  {
    Serial.println("Failed to init 433MHz receiver");
  }
}

void setup_wifi()
{
  delay(10);
  Serial.println();
  Serial.print("Connecting to ");
  Serial.println(SSID);

  WiFi.begin(SSID, PSK);

  while (WiFi.status() != WL_CONNECTED)
  {
    delay(500);
    Serial.print(".");
  }

  Serial.println("");
  Serial.println("WiFi connected");
  Serial.println("IP address: ");
  Serial.println(WiFi.localIP());
}

void reconnect()
{
  while (!client.connected())
  {
    Serial.print("Reconnecting...");
    if (!client.connect("ESP8266Client"))
    {
      Serial.print("failed, rc=");
      Serial.print(client.state());
      Serial.println(" retrying in 5 seconds");
      delay(5000);
    }
  }
}

void loop()
{
  float lv_temp;
  float lv_pressure;
  float lv_humidity;
  unsigned int lv_wind;
  unsigned int lv_rain;
  unsigned int lv_battery;
  uint8_t buflen = sizeof(msg);

  char *messageparts[11];
  char *savepart;
  char *endpart;

  if (!client.connected())
  {
    reconnect();
  }
  client.loop();

  if (radioHead.recv(msg, &buflen))
  {
    Serial.print("New message arrived: ");
    Serial.println((char *)msg);

    // move message to struct
    int fieldcount = 0;
    int charcount = 0;
    char fieldvalue[10];

    // Split imcoming message into parts
    for (int i = 0; i < 11; i++) {

      // this is the first run, so we need to call STRTOK_R with input char array
      if (i == 0) {
        messageparts[i] = strtok_r((char *)msg, "|", &savepart);
      } else {
        // this is a subsequent call of STTOK_R, so we need to call with NULL. This way  the function
        // use the same string like before
        messageparts[i] = strtok_r(NULL, "|", &savepart);
      }
      Serial.println(messageparts[i]);
    }

    endpart = strstr(messageparts[10], "END");

    if (strcmp(messageparts[0], "WW" ) == 0 && endpart )
    {
      Serial.println("message valid");
      //send by MQTT
      client.publish("/WirelessWeather/MessageID", messageparts[1]);
      client.publish("/WirelessWeather/Temperature", messageparts[2]);
      client.publish("/WirelessWeather/Pressure", messageparts[3]);
      client.publish("/WirelessWeather/Humidity", messageparts[4]);
      client.publish("/WirelessWeather/Wind", messageparts[5]);
      client.publish("/WirelessWeather/Rain", messageparts[6]);
      client.publish("/WirelessWeather/WindDir", messageparts[7]);
      client.publish("/WirelessWeather/Battery", messageparts[8]);
      client.publish("/WirelessWeather/Solar", messageparts[9]);
    }
    else
    {
      Serial.println("invalid message");
    }
  }
}

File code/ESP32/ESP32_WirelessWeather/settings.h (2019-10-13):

// WIFI -settings
const char* SSID = "YOUR_SSID";
const char* PSK = "YOUR_PSK";

// MQTT Settings
const char* MQTT_BROKER = "IP_ADDRESS OF MQTT BROKER";
const int MQTT_PORT = 1883;

// Sleep settings for ESP32
const int SLEEP_MIN = 5;

// Sleep settings for ULP co-processor in milli seconds
const int ULP_SLEEP_MS = 10;

// GPIO number for anemometer, please use GPIO, not RTC_GPIO number
const gpio_num_t GPIO_WIND = GPIO_NUM_35;

// GPIO number for tipping bucket (rain sensor), please use GPIO, not RTC_GPIO number
const gpio_num_t GPIO_RAIN = GPIO_NUM_26;

// ADC GPIO number for battery
const int adc_battery = A0;

// ADC GPIO number for solar
const int adc_solar = A3;

// change this value to calibrate the battery voltage
float calib_factor_battery = 1.863; 

// change this value to calibrate the solar voltage
float calib_factor_solar = 1.863;

// Define Pin for I2C VCC
const gpio_num_t i2cVccPin = GPIO_NUM_23;

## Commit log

2019-07-16 Schematics added
    Kikad Files added, Schematics as PDF
    [PCB.kicad_pcb, PCB.sch]
2019-07-20 Schematics Update
    Schematics update, now working I2C Communication. New Code for ATTINYs (less overhead)
    [PCB.sch]
2019-08-06 Small fixes, Solar power added
    [PCB.sch]
2019-08-06 Pictures and BOM
2019-09-03 ESP32-PCB
    Start of development for ESP32 PCB
    [PCB.kicad_pcb, PCB.sch]
2019-09-24 PCB for ESP32
    [PCB.sch]
2019-09-24 Create ulp_count.s
    Assembler code for ESP32 ULP co-processor. This code should be able to count pulses of two distinct gpios
2019-09-26 ESP32 Test Code
2019-09-26 Start of eSP32 development
2019-10-13 ESP32 Code complete
    [PCB.sch]
2019-11-27 Arduino mini code
    [PCB.kicad_pcb, PCB.sch]
2019-12-10 Update BOM, Readme, move files
2019-12-29 Arduino pro mini final
2020-01-07 Schematics for ESP32
2020-04-20 added STL files
    [Anemometer-Lagerschale (1).stl, Anemometer-Lagerschale.stl, Anemometer-lower-part v16.stl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]
